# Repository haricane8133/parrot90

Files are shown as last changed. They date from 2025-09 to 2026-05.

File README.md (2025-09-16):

# Parrot 90

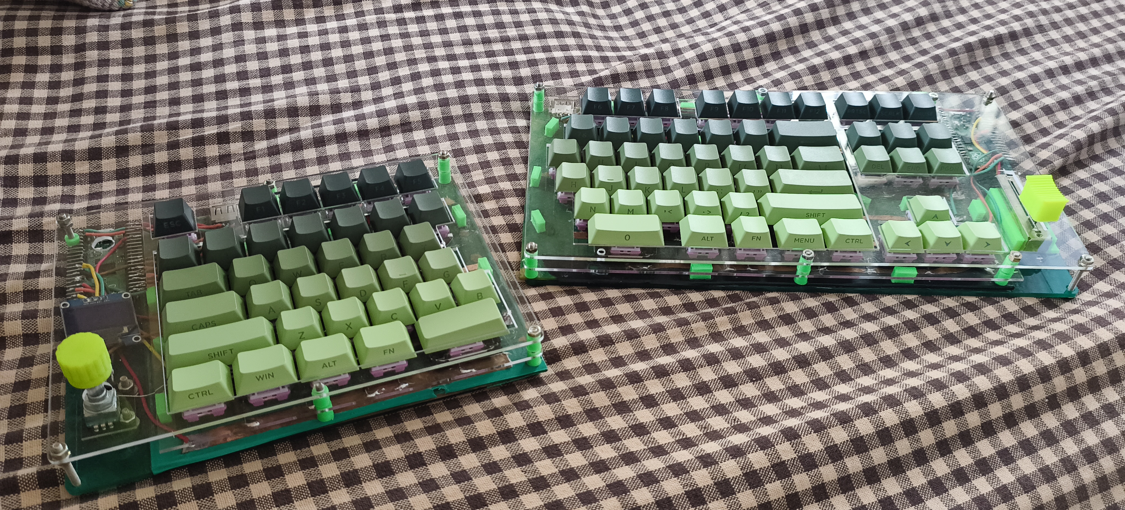
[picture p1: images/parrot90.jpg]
Parrot90

BongoCatSlow
BongoCatFast

Here is a video demo of the keyboard
[https://youtu.be/1Eb73ttOM24](https://youtu.be/1Eb73ttOM24)

This is a home made custom mechanical keyboard. Here are the important points to note
1. Fully home made (including circuit board, excluding switches and keycaps obviously)
2. Circuit board has tin mask and solder mask; designed with old Adobe Photoshop!
3. Hot Swappable
4. TKL Split (90 switches)
5. Rotary encoder
6. Slider Potentiometer (code support coming up)
7. OLED display that shows WPM amd bongo cat gif while typing!
8. Python powered (KMK firmware, CircuitPython)
9. WebSockets / Bluetooth support to connect keyboard with anything (code support coming up)
10. Sandwich type acrylic laser cut case

Here are the switches and keycaps I bought and used for my build (procured through Indian distributors)
* [Akko V3 Creamy Purple Pro](https://en.akkogear.com/product/akko-v3-creamy-purple-pro-switch/)
* [Veekos Forest Gradient Keycap Set](https://www.veekos.com/product/veekos-forest-gradient-keycap-set-135-key/)

Checkout the README files within [/hardware](./hardware/) and [/software](./software/) to know how to build and use one yourself.

But do note that serious hardwork is required as this is a chill non-professional work done with a lot of homebrew / make-shift tools and stuff.

Thanks to @vu2ow for helping out with the build!

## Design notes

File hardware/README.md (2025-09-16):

# Parrot90 Hardware

## Plate / Sandwich case
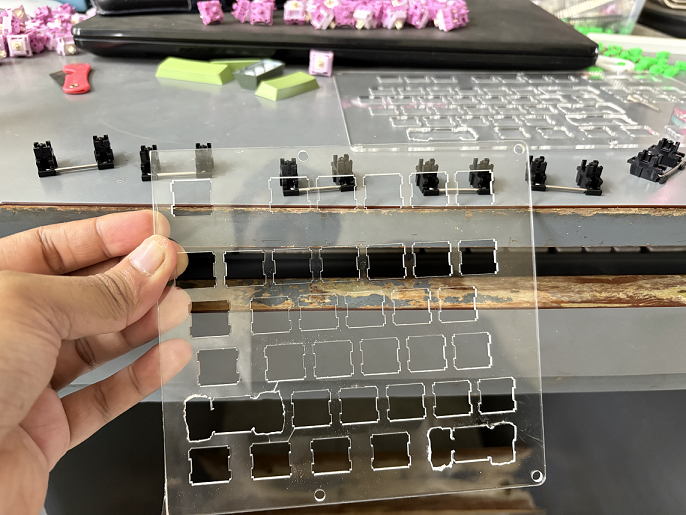
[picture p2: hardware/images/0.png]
Plate design

* The plate design files are available in the `./plate` directory.
* You need to laser cut 1.5mm acrylic sheet. If you use a thicker sheet, then you risk the stabilizers not fixing properly in your plate.
* The files `./plate/left_README.md` and `./plate/right_README.md` files contain the details of the design/layout of the keyboard and the open source websites used.

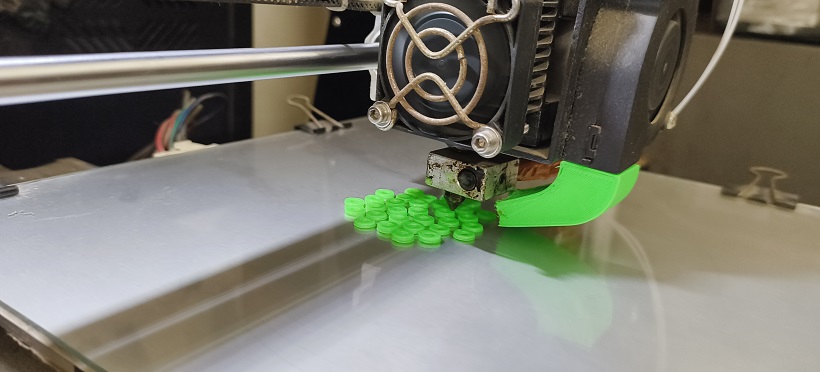
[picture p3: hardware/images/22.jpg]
3D printed fit

If the fit of the switch in the plate and the hotswap socket in the circuit board do not match properly, you need to 3D print some spacers... More details on this below.

## Circuit
* The circuit is already designed. You can just use the images from `./circuit` directory.
* Note: Use caution while using chemicals. Use internet to learn more before doing.

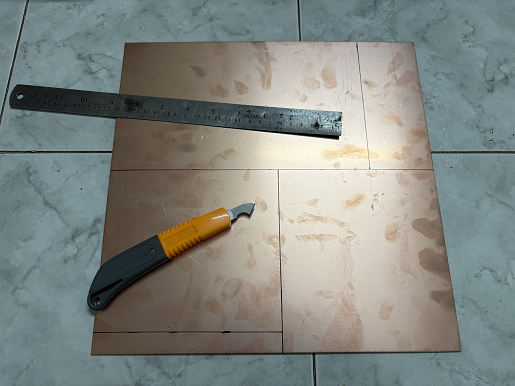
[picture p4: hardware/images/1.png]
Cut the circuit board into right dimensions


Cut the circuit board into right dimensions

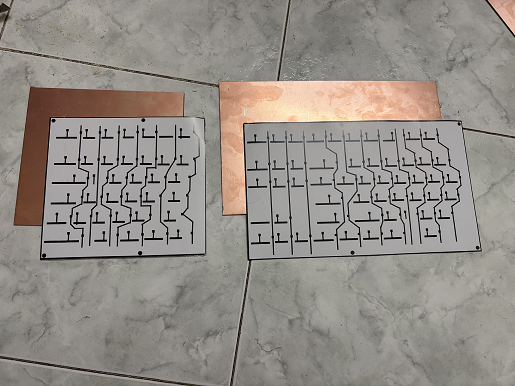
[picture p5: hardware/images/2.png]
Print the circuits in a shiny photo paper using a Laser printer. Make sure to flip the image


Print the circuits in a shiny photo paper using a Laser printer. Make sure to flip the image

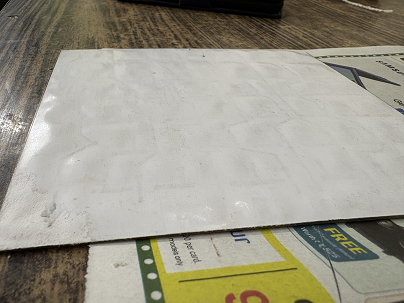
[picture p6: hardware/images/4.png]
... until you see the paper embossing along the plastic


... until you see the paper embossing along the plastic

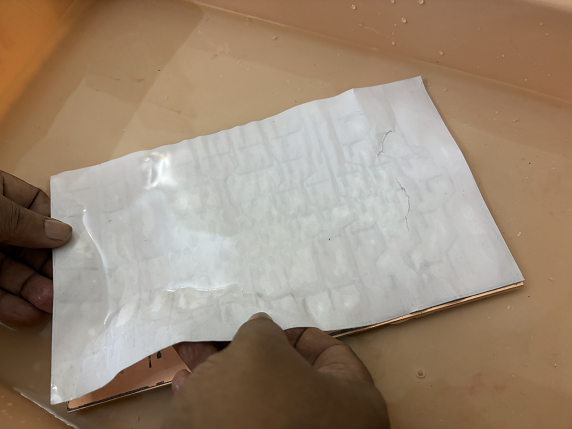
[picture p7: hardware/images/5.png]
Remove the paper. You can use water too


Remove the paper. You can use water too

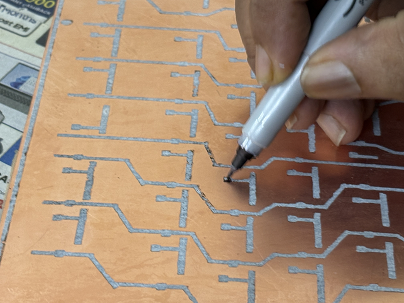
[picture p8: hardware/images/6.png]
Use a permanent marker to sketch out the parts where circuit has broken


Use a permanent marker to sketch out the parts where circuit has broken

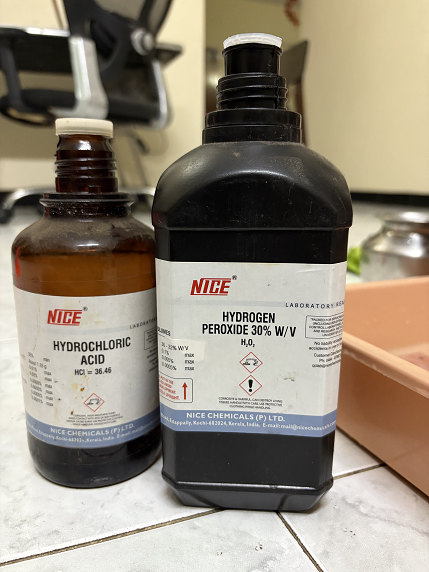
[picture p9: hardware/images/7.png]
Get the chemicals ready for bathing the circuit. Mix them in a plastic container with water


Get the chemicals ready for bathing the circuit. Mix them in a plastic container with water

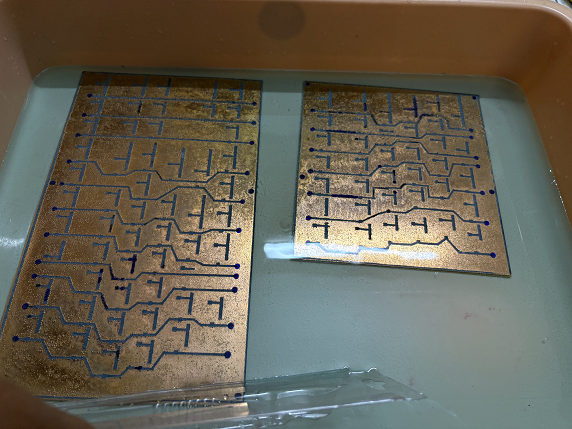
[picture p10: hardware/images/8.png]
Bathe the circuit boards. Make sure to change proportions according to reaction


Bathe the circuit boards. Make sure to change proportions according to reaction

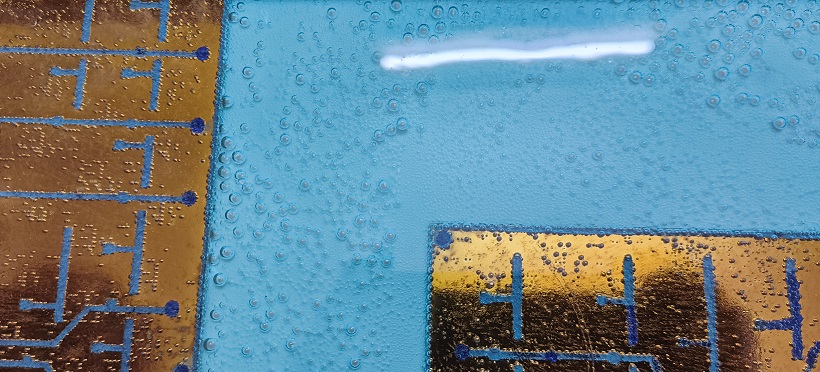
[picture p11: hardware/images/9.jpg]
Fizz indicates that the copper is being dissolved out


Fizz indicates that the copper is being dissolved out

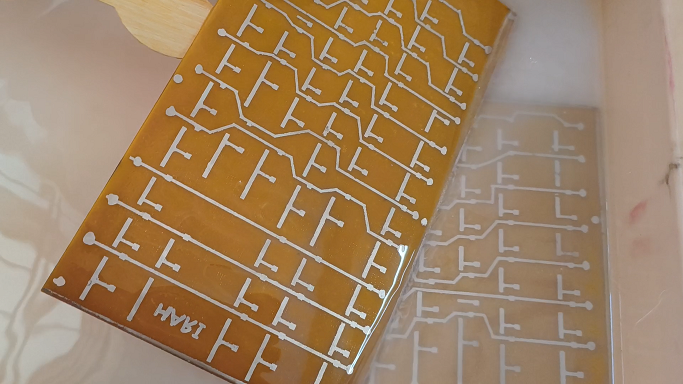
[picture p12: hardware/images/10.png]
Tinning


Wash the boards and prepare them for tinning. Bathe them in Tin Chloride and HCL.

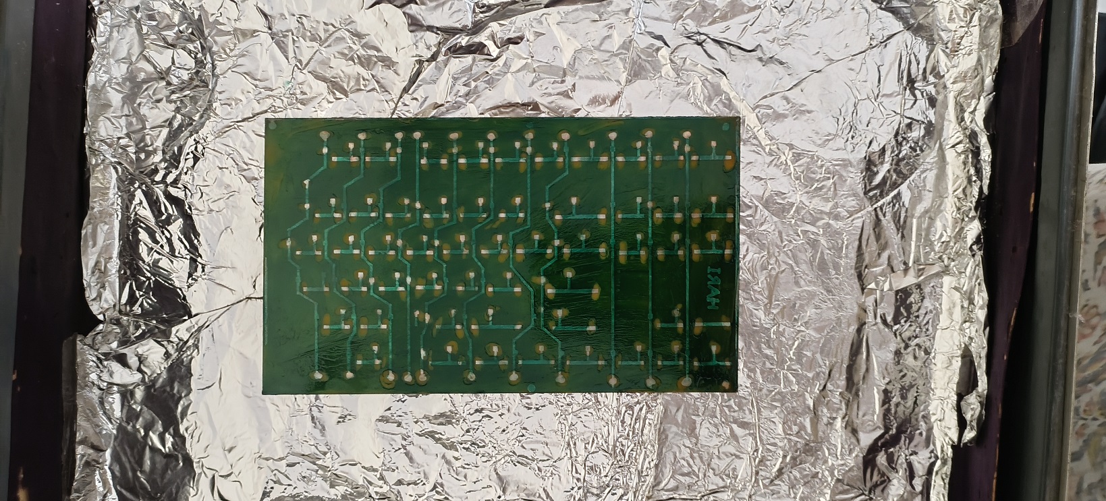
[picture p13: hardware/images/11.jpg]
Use a brush and paint solder mask, except in the places where we have copper/tin


Use a brush and paint solder mask, except in the places where we have copper/tin

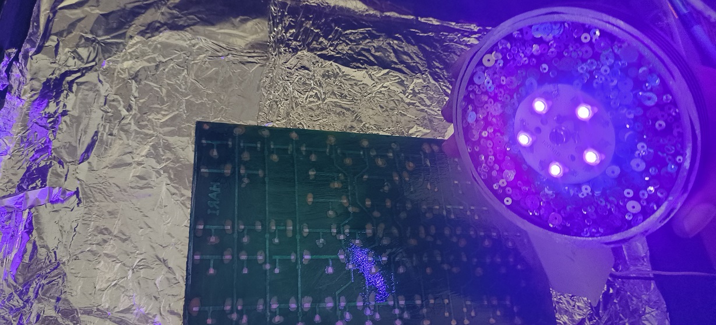
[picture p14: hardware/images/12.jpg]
It is nice to have UV lights shined on them to harden them. Else sunlight for a long time


It is nice to have UV lights shined on them to harden them. Else sunlight for a long time.
In case you notice that you put solder mask over circuit, you need to scrape the layer off later.

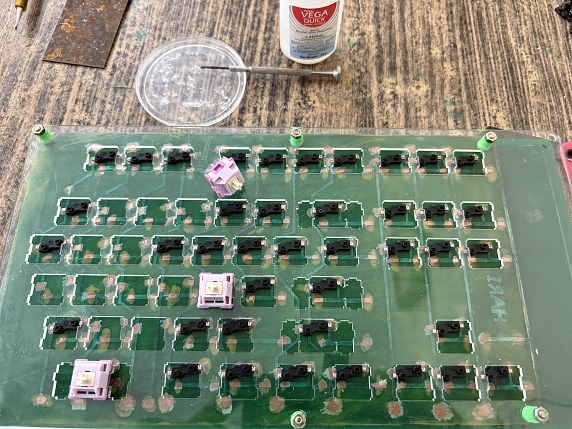
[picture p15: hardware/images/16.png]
Fix the hotswap sockets


Next stage is to assemble hotswap sockets. Here is what you need to do
* First glue the circuit board to the base acrylic plate.
* Second align the switch plate on to the base plate and fasten them tightly.
* Try attach the hotswap sockets to a switch and insert it into the plate.
* Ensure that the bottom of the sockets is exactly touching the circuit boards and the switch is set in the plate.
* Follow the next step in case you need some spacers to be placed to adjust the fit. This is critical
* Then place a quick glue drop on the bottom of the socket and insert the switch into the plate.
* Wait for sometime and pull out the switch. The hotswap should now be fixed to the circuit board at the right place.
* Repeat this for all the switches.

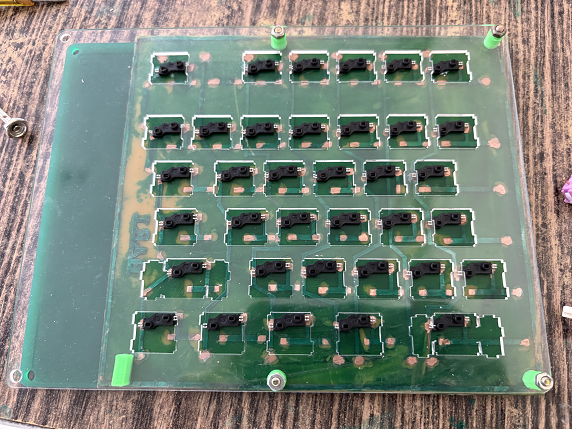
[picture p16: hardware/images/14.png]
You'll have this now


You'll have this now

If the fit of the switch in the plate and the hotswap socket in the circuit board do not match properly, you need to 3D print some spacers...

If the fit of the switch in the plate and the hotswap socket in the circuit board do not match properly, you need to 3D print some spacers...

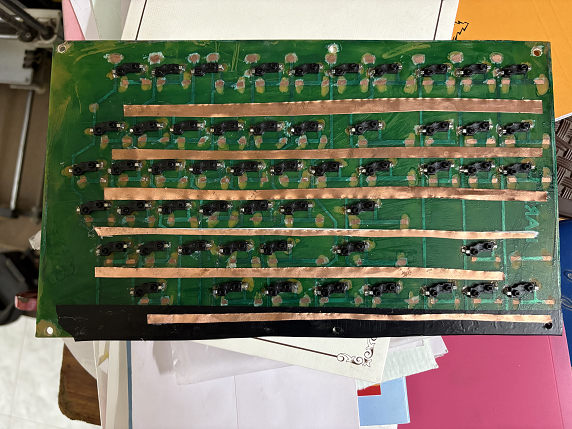
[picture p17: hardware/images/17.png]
Then glue some copper strips for the rows


Then glue some copper strips for the rows

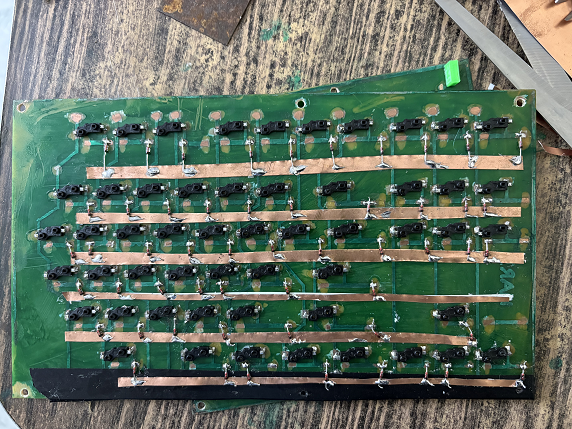
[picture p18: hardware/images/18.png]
Then solder the diodes


Then solder the diodes

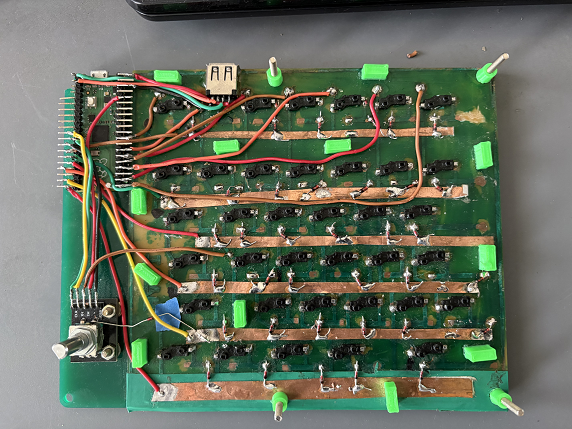
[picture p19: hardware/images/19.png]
Then solder everything else according to the pins marked in code


Then solder everything else according to the pins marked in code. Note the UCB connection between the left half and the right half

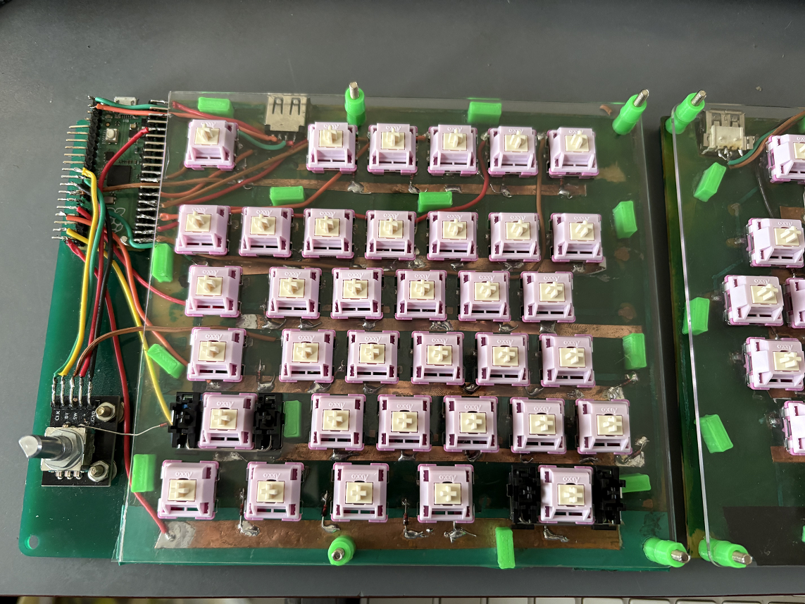
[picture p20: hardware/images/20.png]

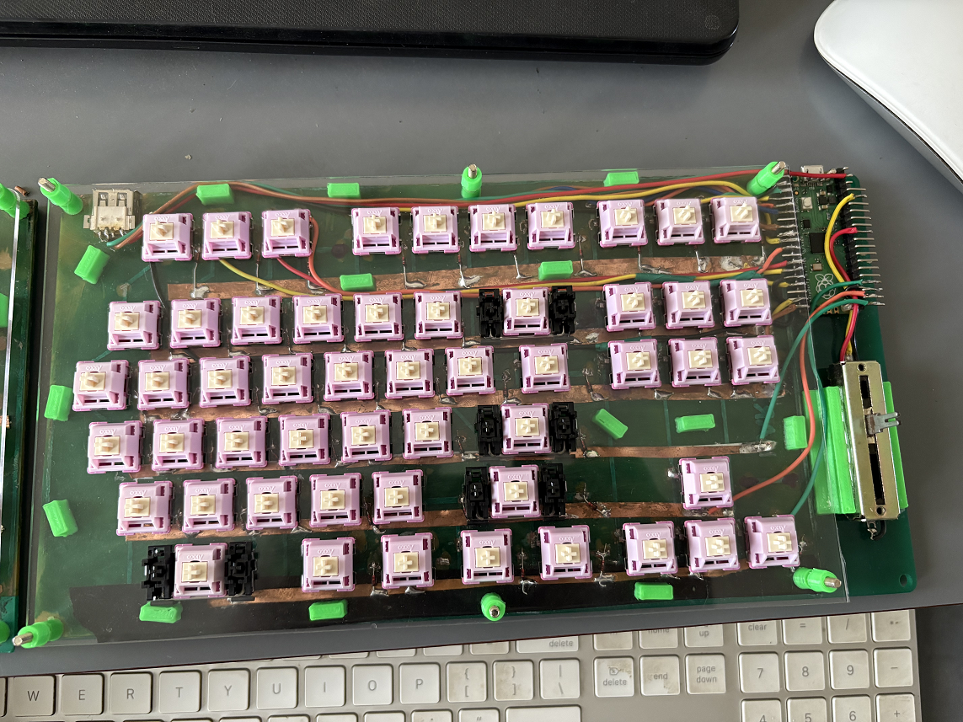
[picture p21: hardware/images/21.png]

Fix the stabilizers, the switches, keycaps and the other plate layers

Fix the stabilizers, the switches, keycaps and the other plate layers

### Some other details
* If you would prefer to handwire instead of a circuit board, that can also be done. Just glue the hotswap directly to the base plate and then solder wires.
* The circuit was designed in Adobe Photoshop by working with images (png, jpg, etc).
* We just have to ensure that all the sizes are accurate - size of switch, size of hotswap socket, etc...

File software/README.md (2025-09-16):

# Parrot90 Software
1. Flash CircuitPython 9.2.8 on the two Raspberry PI Picos. Instructions [here](https://circuitpython.org/)
2. Install latest KMK (copy KMK) to the two picos. Instructions [here](https://github.com/KMKfw/kmk_firmware)
3. Install all library dependencies as mentioned in the following section.
4. Transfer the code from this folder to the two picos
5. Make sure to the underscore from `code.py` and `boot.py` for respective Picos.

### Dependencies
* https://github.com/adafruit/Adafruit_CircuitPython_DisplayIO_SSD1306/releases/download/3.0.3/adafruit-circuitpython-displayio-ssd1306-py-3.0.3.zip
* https://github.com/adafruit/Adafruit_CircuitPython_Display_Text/releases/download/3.3.3/adafruit-circuitpython-display-text-py-3.3.3.zip
* https://github.com/adafruit/Adafruit_CircuitPython_ImageLoad/releases/download/1.24.4/adafruit-circuitpython-imageload-9.x-mpy-1.24.4.zip
Note: After downloading all libraries, just rename their parent folders to the actual library and flatten out the lib folder in the parent so that code can import properly. For Adafruit_CircuitPython_DisplayIO_SSD1306, rename the py file to __init__.py also.

### Debug
If you need to debug through serial port, use the following -
`python -m serial.tools.miniterm COMX 115200`

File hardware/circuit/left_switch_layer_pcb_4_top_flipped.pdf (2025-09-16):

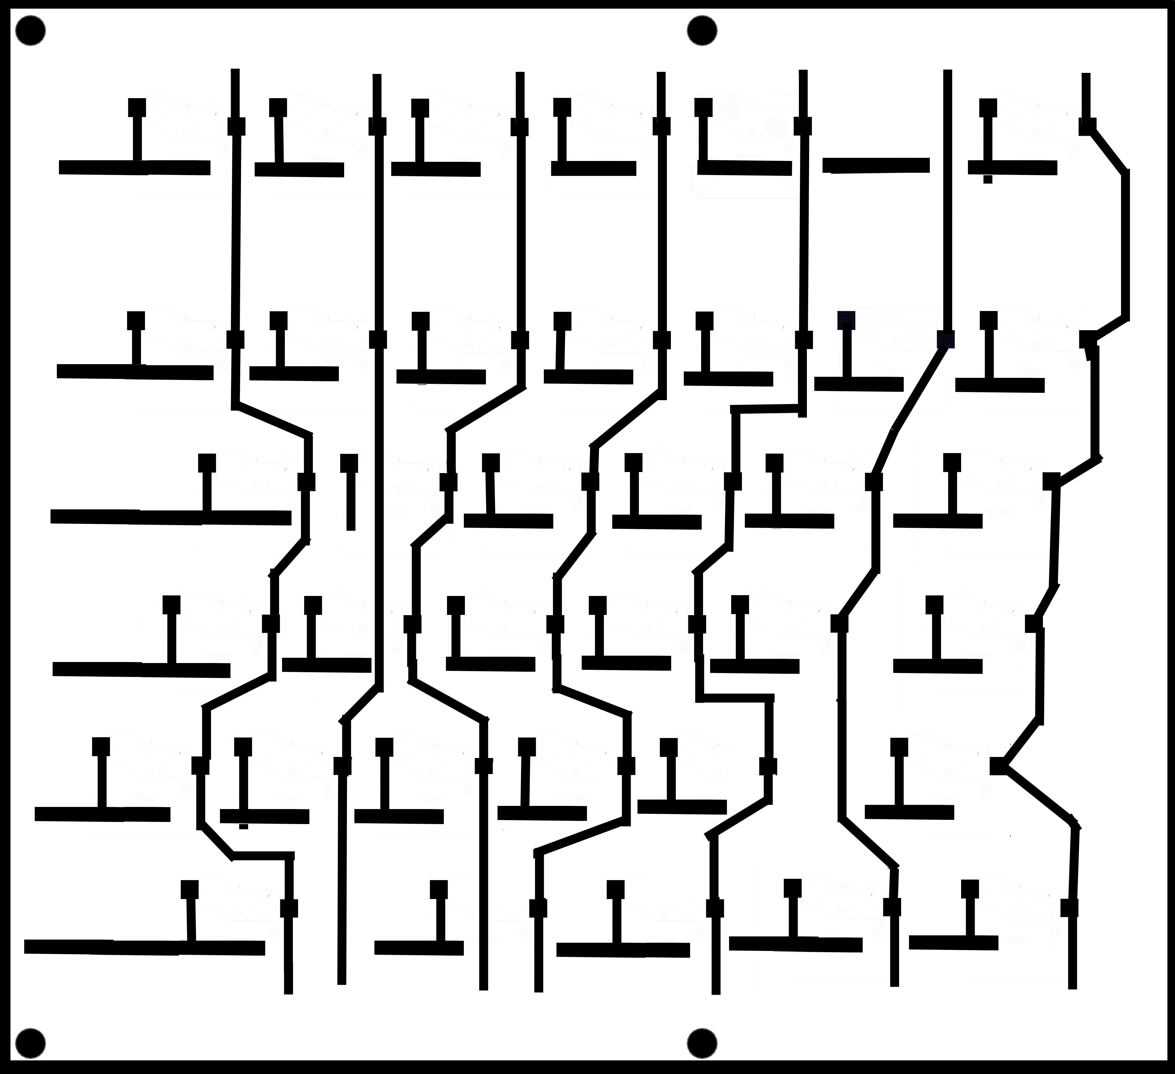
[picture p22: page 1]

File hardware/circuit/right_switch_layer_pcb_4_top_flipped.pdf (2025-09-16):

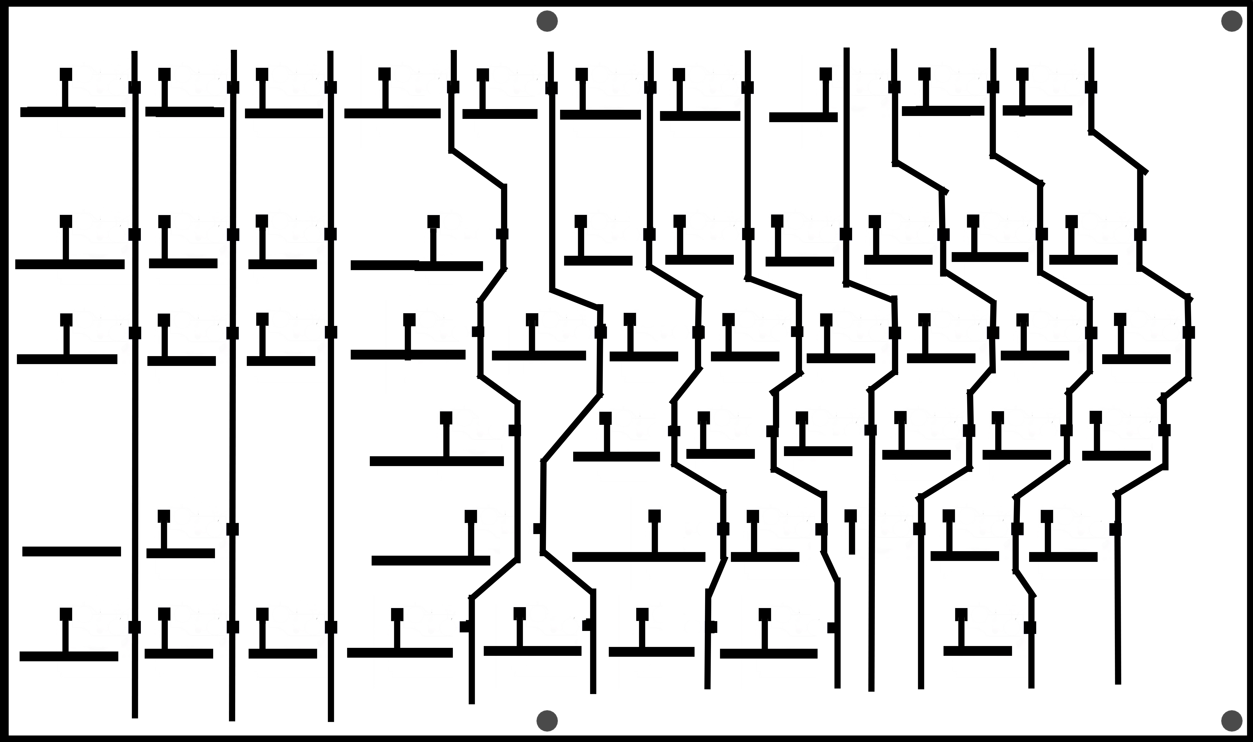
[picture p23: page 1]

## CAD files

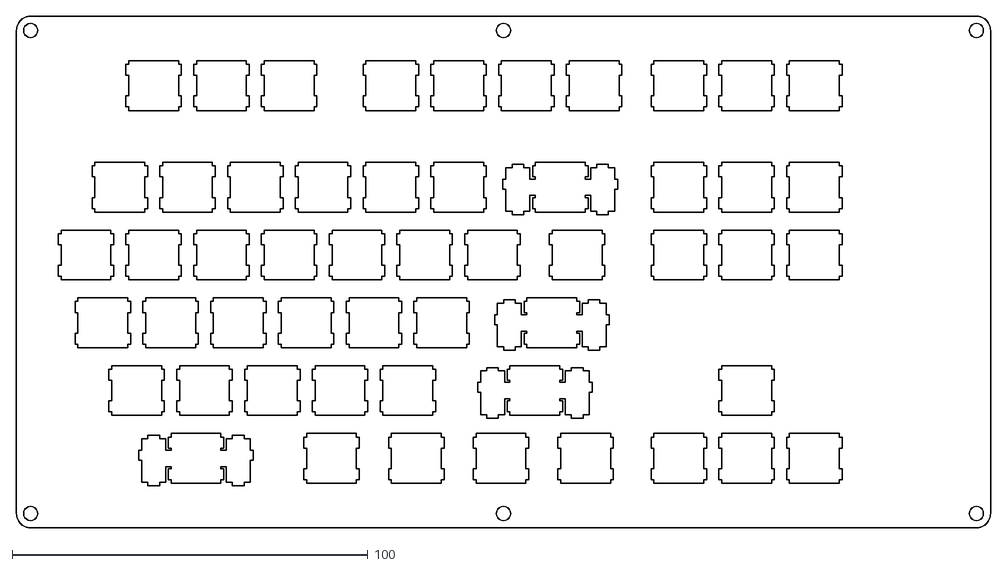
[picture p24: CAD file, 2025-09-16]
hardware/plate/right_switch_layer.dxf
273.8 x 143.8

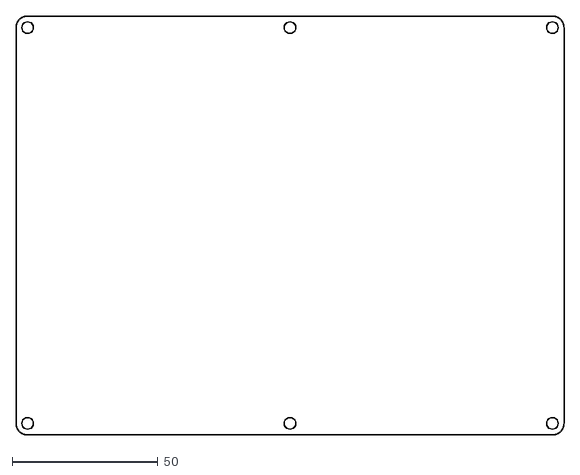
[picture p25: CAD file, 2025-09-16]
hardware/plate/left_bottom_layer.dxf
188.1 x 143.8

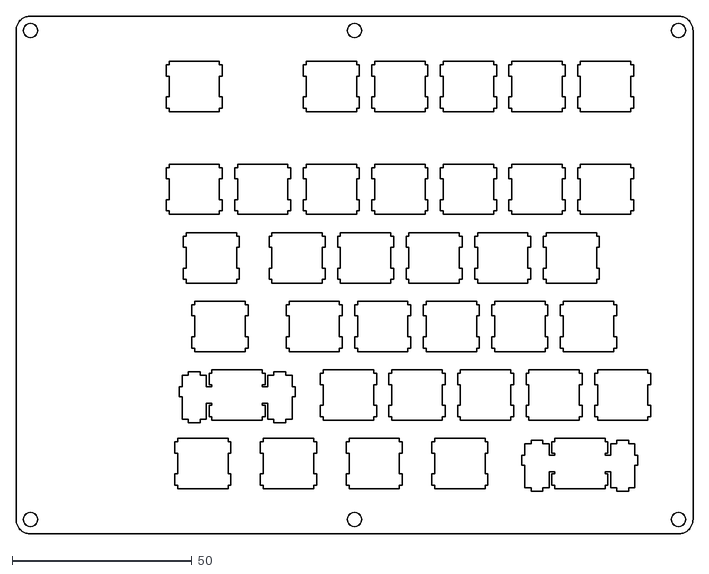
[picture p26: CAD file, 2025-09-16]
hardware/plate/left_switch_layer.dxf
188.1 x 143.8

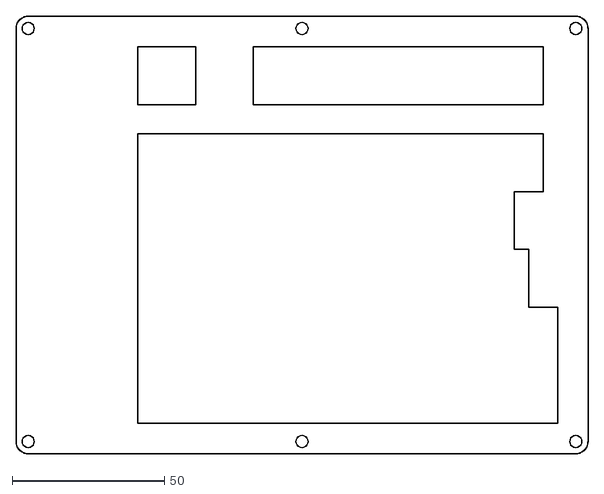
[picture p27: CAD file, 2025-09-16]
hardware/plate/left_top_layer.dxf
188.1 x 143.8

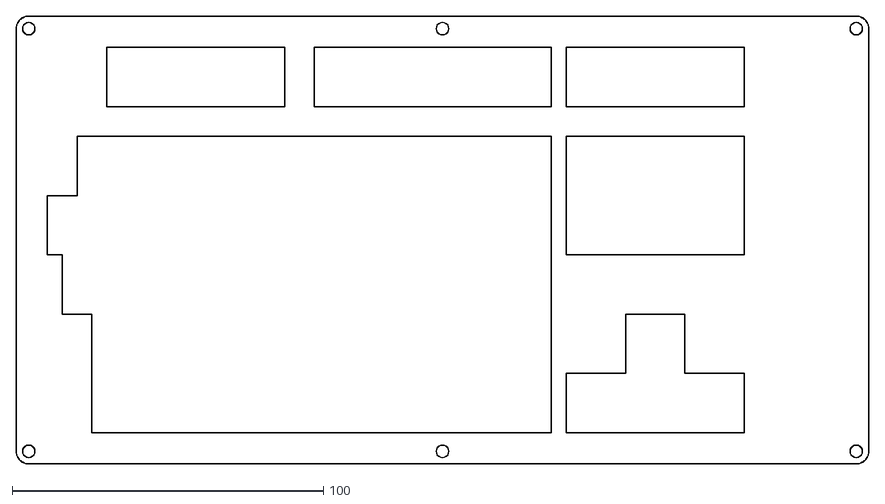
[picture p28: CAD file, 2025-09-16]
hardware/plate/right_top_layer.dxf
273.8 x 143.8

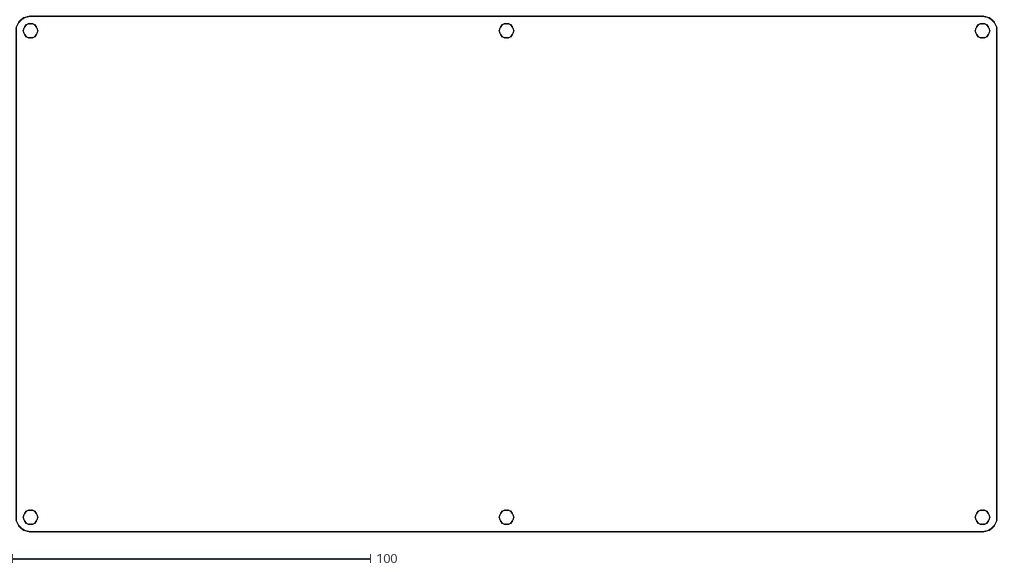
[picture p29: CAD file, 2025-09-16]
hardware/plate/right_bottom_layer.dxf
273.8 x 143.8

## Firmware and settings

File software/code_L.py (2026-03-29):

import sys, time, board, microcontroller # type: ignore

# if microcontroller.nvm[1] == 1:
#     sys.exit()

print("LHS: Starting code.py")

from kmk.kmk_keyboard import KMKKeyboard
from kmk.keys import KC
from kmk.scanners import DiodeOrientation


# Setup
print("LHS: Configuring Keyboard")

keyboard = KMKKeyboard()
keyboard.debug_enabled = False
# if microcontroller.nvm[1] == 1:
#     keyboard.debug_enabled = False

from kmk.modules.split import Split, SplitType, SplitSide
split = Split(
    split_side=SplitSide.LEFT,
    split_target_left=True,
    split_flip=False,
    split_type=SplitType.UART,
    uart_interval = 1,
    split_mapping={
        'rows': 6,
        'left_cols': 7,
        'right_cols': 11,
        'right_start': 66,
        'split_flip': False,
    },
    # use_pio=True,
    data_pin=board.GP1,
    data_pin2=board.GP0,
    # uart_flip = False,
)
split.debug_enabled = False
keyboard.modules.append(split)

from kmk.modules.layers import Layers
keyboard.modules.append(Layers())

from kmk.extensions.media_keys import MediaKeys
keyboard.extensions.append(MediaKeys())

# Asymmetric split: left half has 7 columns, right half has 11 columns.
# Keyboard Config
keyboard.col_pins = (board.GP22, board.GP21, board.GP20, board.GP19, board.GP18, board.GP17, board.GP16)
keyboard.row_pins = (board.GP10, board.GP11, board.GP12, board.GP13, board.GP14, board.GP15)
keyboard.diode_orientation = DiodeOrientation.COL2ROW

# Keyboard Matrices
macMatrix = [
    [
        KC.ESC,   KC.NO,    KC.NO,   KC.NO,    KC.NO,   KC.NO,   KC.NO,                   KC.MRWD, KC.MPLY, KC.MFFD, KC.NO,   KC.MUTE,  KC.VOLD,  KC.VOLU,   KC.NO,    KC.NO,    KC.NO,   KC.NO,
        KC.GRAVE, KC.N1,    KC.N2,   KC.N3,    KC.N4,   KC.N5,   KC.N6,                   KC.N7,   KC.N8,   KC.N9,   KC.N0,   KC.MINUS, KC.EQUAL, KC.NO,     KC.BSPC,  KC.MO(1), KC.HOME, KC.PGUP,
        KC.TAB,   KC.Q,     KC.W,    KC.E,     KC.R,    KC.NO,   KC.T,                    KC.Y,    KC.U,    KC.I,    KC.O,    KC.P,     KC.LBRC,  KC.RBRC,   KC.BSLS,  KC.DEL,   KC.END,  KC.PGDN,
        KC.CAPS,  KC.A,     KC.S,    KC.D,     KC.F,    KC.NO,   KC.G,                    KC.H,    KC.J,    KC.K,    KC.L,    KC.SCLN,  KC.QUOT,  KC.NO,     KC.ENT,   KC.MO,    KC.NO,   KC.NO,
        KC.LSFT,  KC.MUTE,  KC.Z,    KC.X,     KC.C,    KC.V,    KC.B,                    KC.N,    KC.M,    KC.COMM, KC.NO,   KC.DOT,   KC.SLSH,  KC.RSHIFT, KC.NO,    KC.NO,    KC.UP,   KC.NO,
        KC.LCTL,  KC.MO(1), KC.LALT, KC.LGUI,  KC.NO,   KC.NO,   KC.SPC,                  KC.NO,   KC.SPC,  KC.NO,   KC.NO,   KC.RGUI,  KC.RALT,  KC.MO(1),  KC.RCTRL, KC.LEFT,  KC.DOWN, KC.RIGHT
    ],
    [
        KC.TRNS,  KC.TRNS, KC.F1,   KC.F2,    KC.F3,   KC.F4,   KC.F5,                    KC.F6,    KC.F7,   KC.F8,   KC.NO,   KC.F9,   KC.F10,  KC.F11,  KC.F12,  KC.F13,  KC.F14,  KC.F15,
        KC.TRNS,  KC.TRNS, KC.TRNS, KC.TRNS,  KC.TRNS, KC.TRNS, KC.TRNS,                  KC.TRNS,  KC.TRNS, KC.TRNS, KC.TRNS, KC.TRNS, KC.TRNS, KC.TRNS, KC.TRNS, KC.TRNS, KC.TRNS, KC.TRNS,
        KC.TRNS,  KC.TRNS, KC.TRNS, KC.TRNS,  KC.TRNS, KC.TRNS, KC.TRNS,                  KC.TRNS,  KC.TRNS, KC.TRNS, KC.TRNS, KC.TRNS, KC.TRNS, KC.TRNS, KC.TRNS, KC.TRNS, KC.TRNS, KC.TRNS,
        KC.TRNS,  KC.TRNS, KC.TRNS, KC.TRNS,  KC.TRNS, KC.TRNS, KC.TRNS,                  KC.TRNS,  KC.TRNS, KC.TRNS, KC.TRNS, KC.TRNS, KC.TRNS, KC.TRNS, KC.TRNS, KC.TRNS, KC.TRNS, KC.TRNS,
        KC.TRNS,  KC.TRNS, KC.TRNS, KC.TRNS,  KC.TRNS, KC.TRNS, KC.TRNS,                  KC.TRNS,  KC.TRNS, KC.TRNS, KC.TRNS, KC.TRNS, KC.TRNS, KC.TRNS, KC.TRNS, KC.TRNS, KC.TRNS, KC.TRNS,
        KC.TRNS,  KC.TRNS, KC.TRNS, KC.TRNS,  KC.TRNS, KC.TRNS, KC.TRNS,                  KC.TRNS,  KC.TRNS, KC.TRNS, KC.TRNS, KC.TRNS, KC.TRNS, KC.TRNS, KC.TRNS, KC.TRNS, KC.TRNS, KC.TRNS
    ],
]
winMatrix = [
    [
        KC.ESC,   KC.NO,    KC.F1,   KC.F2,    KC.F3,   KC.F4,   KC.F5,                   KC.F6,   KC.F7,   KC.F8,   KC.NO,   KC.F9,    KC.F10,   KC.F11,    KC.F12,    KC.PSCREEN,       KC.SLCK, KC.PAUSE,
        KC.GRAVE, KC.N1,    KC.N2,   KC.N3,    KC.N4,   KC.N5,   KC.N6,                   KC.N7,   KC.N8,   KC.N9,   KC.N0,   KC.MINUS, KC.EQUAL, KC.NO,     KC.BSPC,   KC.LT(1, KC.INS), KC.HOME, KC.PGUP,
        KC.TAB,   KC.Q,     KC.W,    KC.E,     KC.R,    KC.NO,   KC.T,                    KC.Y,    KC.U,    KC.I,    KC.O,    KC.P,     KC.LBRC,  KC.RBRC,   KC.BSLS,   KC.DEL,           KC.END,  KC.PGDN,
        KC.CAPS,  KC.A,     KC.S,    KC.D,     KC.F,    KC.NO,   KC.G,                    KC.H,    KC.J,    KC.K,    KC.L,    KC.SCLN,  KC.QUOT,  KC.NO,     KC.ENT,    KC.NO,            KC.NO,   KC.NO,
        KC.LSFT,  KC.MUTE,  KC.Z,    KC.X,     KC.C,    KC.V,    KC.B,                    KC.N,    KC.M,    KC.COMM, KC.NO,   KC.DOT,   KC.SLSH,  KC.RSHIFT, KC.NO,     KC.NO,            KC.UP,   KC.NO,
        KC.LCTL,  KC.MO(1), KC.LGUI, KC.LALT,  KC.NO,   KC.NO,   KC.SPC,                  KC.NO,   KC.SPC,  KC.NO,   KC.NO,   KC.RALT,  KC.RGUI,  KC.MO(1),  KC.RCTRL,  KC.LEFT,          KC.DOWN, KC.RIGHT
    ],
    [
        KC.TRNS,  KC.TRNS, KC.NO,   KC.NO,   KC.NO,   KC.NO,   KC.NO,                     KC.MPRV,  KC.MPLY, KC.MNXT, KC.TRNS, KC.MUTE, KC.VOLD, KC.VOLU, KC.TRNS, KC.TRNS, KC.TRNS, KC.TRNS,
        KC.TRNS,  KC.TRNS, KC.TRNS, KC.TRNS, KC.TRNS, KC.TRNS, KC.TRNS,                   KC.TRNS,  KC.TRNS, KC.TRNS, KC.TRNS, KC.TRNS, KC.TRNS, KC.TRNS, KC.TRNS, KC.TRNS, KC.TRNS, KC.TRNS,
        KC.TRNS,  KC.TRNS, KC.TRNS, KC.TRNS, KC.TRNS, KC.TRNS, KC.TRNS,                   KC.TRNS,  KC.TRNS, KC.TRNS, KC.TRNS, KC.TRNS, KC.TRNS, KC.TRNS, KC.TRNS, KC.TRNS, KC.TRNS, KC.TRNS,
        KC.TRNS,  KC.TRNS, KC.TRNS, KC.TRNS, KC.TRNS, KC.TRNS, KC.TRNS,                   KC.TRNS,  KC.TRNS, KC.TRNS, KC.TRNS, KC.TRNS, KC.TRNS, KC.TRNS, KC.TRNS, KC.TRNS, KC.TRNS, KC.TRNS,
        KC.TRNS,  KC.TRNS, KC.TRNS, KC.TRNS, KC.TRNS, KC.TRNS, KC.TRNS,                   KC.TRNS,  KC.TRNS, KC.TRNS, KC.TRNS, KC.TRNS, KC.TRNS, KC.TRNS, KC.TRNS, KC.TRNS, KC.TRNS, KC.TRNS,
        KC.TRNS,  KC.TRNS, KC.TRNS, KC.TRNS, KC.TRNS, KC.TRNS, KC.TRNS,                   KC.TRNS,  KC.TRNS, KC.TRNS, KC.TRNS, KC.TRNS, KC.TRNS, KC.TRNS, KC.TRNS, KC.TRNS, KC.TRNS, KC.TRNS
    ],
]

if(microcontroller.nvm[2] == 0):
    keyboard.keymap = winMatrix
else:
    keyboard.keymap = macMatrix


# Rotary Encoder (only the rotating part. The button is included in the above keyboard matrix)
from kmk.modules.encoder import EncoderHandler
encoder_handler = EncoderHandler()
encoder_handler.pins = [(board.GP9, board.GP8, None, False)]
encoder_handler.map = [[(KC.VOLD, KC.VOLU, KC.NO)]]
keyboard.modules.append(encoder_handler)





print("LHS: Starting Display")

ENABLE_GIF_WPM = microcontroller.nvm[3] == 1

from random import randint
import busio, displayio, terminalio, i2cdisplaybus
from adafruit_display_text import label
from adafruit_displayio_ssd1306 import SSD1306
from kmk.extensions.lock_status import LockStatus


NAME = "Parrot90"
message1 = ["Greeny", "Parrot", "Parakeet", "Canopy", "Parakeeb", "Leaves", "Forrest", "KeeBird"]

WIDTH = 128
HEIGHT = 64
ROTATION = 0
BORDER = 1


displayio.release_displays()

# --- Initialize I2C
i2c = busio.I2C(board.GP3, board.GP2)   # SCL=GP3, SDA=GP2

# --- Create the I2C display bus
display_bus = displayio.I2CDisplay(i2c, device_address=0x3C)


# i2c = busio.I2C(scl=board.GP3, sda=board.GP2)
# i2c_display = i2cdisplaybus.I2CDisplayBus(i2c, device_address=0x3C)

display = SSD1306(display_bus, width=WIDTH, height=HEIGHT, rotation=ROTATION)

# Create the root group
mainGrp = displayio.Group()


display.root_group = mainGrp

# Outer white background
color_bitmap = displayio.Bitmap(WIDTH, HEIGHT, 1)
color_palette = displayio.Palette(1)
color_palette[0] = 0xFFFFFF
bg_sprite = displayio.TileGrid(color_bitmap, pixel_shader=color_palette, x=0, y=0)

# Border outline only (palette index 0 will be made transparent)
border_bitmap = displayio.Bitmap(WIDTH, HEIGHT, 2)
border_palette = displayio.Palette(2)
border_palette[0] = 0x000000           # interior (will be made transparent)
border_palette[1] = 0xFFFFFF           # border color (white)

# Draw border lines (only set index 1 on the outline pixels)
for x in range(WIDTH):
    border_bitmap[x, 0] = 1            # top
    border_bitmap[x, HEIGHT - 1] = 1   # bottom
for y in range(HEIGHT):
    border_bitmap[0, y] = 1            # left
    border_bitmap[WIDTH - 1, y] = 1    # right

border_sprite = displayio.TileGrid(border_bitmap, pixel_shader=border_palette, x=0, y=0)



# Banner
banner = label.Label(terminalio.FONT, text=NAME, color=0xFFFFFF, x=18, y=7, scale=2)

# Mode
mode_text = '"' + message1[randint(0, len(message1)-1)] + '"'
if microcontroller.nvm[1] == 1:
    mode_text = "<service mode>"
mode_label = label.Label(terminalio.FONT, text=mode_text, color=0xFFFFFF, x=3, y=23)

# Host
hostText = "<Mac>" if microcontroller.nvm[2] else "<Win>"
host_label = label.Label(terminalio.FONT, text=hostText, color=0xFFFFFF, x=93, y=23)

# Caps Lock symbol
caps_label1 = label.Label(terminalio.FONT, text="^", color=0xFFFFFF, x=5, y=17, scale=2)
caps_label2 = label.Label(terminalio.FONT, text="^", color=0xFFFFFF, x=115, y=17, scale=2)

class _LockStatus(LockStatus):
    def after_hid_send(self, sandbox):
        super().after_hid_send(sandbox)
        if self.get_caps_lock():
            if caps_label1 not in mainGrp:
                mainGrp.append(caps_label1)
            if caps_label2 not in mainGrp:
                mainGrp.append(caps_label2)
        else:
            if caps_label1 in mainGrp:
                mainGrp.remove(caps_label1)
            if caps_label2 in mainGrp:
                mainGrp.remove(caps_label2)

keyboard.extensions.append(_LockStatus())

# The big Hari logo
hari_label = label.Label(terminalio.FONT, text="HARI", color=0xFFFFFF, x=20, y=46, scale=4)

# -------------------------------
# Bongo Cat Gif
# -------------------------------
import adafruit_imageload

keys_typed = 0
type_start_time = None
last_key_time = None
last_oled_wpm_time = None
last_oled_gif_time = time.monotonic()
last_oled_loop_time = None
current_gif_type = 0 # 0 means slow cat gif and 1 means fast cat gif

OLED_MIN_LOOP_INTERVAL = 0.10
WPM_UPDATE_INTERVAL = 0.5
COUNT_RESET_TIME = 5
GIF_WPM_THRESHOLD = 10
GIF_TIME_THRESHOLD = 1
GIF_SLOW_UPDATE_INTERVAL = 0.25
GIF_FAST_UPDATE_INTERVAL = 0.20
DISPLAY_TYPING_SUPPRESS = 0.12

# Load frames
def load_animation(path, frame_count):
    frames = []
    for i in range(frame_count):
        bmp, pal = adafruit_imageload.load(f"{path}/{i}.bmp",
                                           bitmap=displayio.Bitmap,
                                           palette=displayio.Palette)
        frames.append((bmp, pal))
    return frames

cat_slow_frames = load_animation("/images/gif_slow", 5)
cat_fast_frames = load_animation("/images/gif_fast", 3)


# Setup TileGrid for display
current_frame = 0

bmp, pal = cat_slow_frames[0]
anim_sprite = None
if ENABLE_GIF_WPM:
    anim_sprite = displayio.TileGrid(bmp, pixel_shader=pal, x=30, y=28)

def display_is_busy():
    if split._uart is not None and split._uart.in_waiting > 0:
        return True
    if last_key_time is not None and (time.monotonic() - last_key_time) < DISPLAY_TYPING_SUPPRESS:
        return True
    return False

def show_frame(bmp, pal):
    global anim_sprite, current_gif_type, last_oled_gif_time, GIF_SLOW_UPDATE_INTERVAL, GIF_FAST_UPDATE_INTERVAL
    if anim_sprite is None:
        return False

    now = time.monotonic()

    update_interval = GIF_SLOW_UPDATE_INTERVAL
    if (current_gif_type != 0):
        update_interval = GIF_FAST_UPDATE_INTERVAL
    
    if(now - last_oled_gif_time) > update_interval:
        anim_sprite.bitmap = bmp
        anim_sprite.pixel_shader = pal
        last_oled_gif_time = now
        return True
    return False


# Animation update
def update_animation(wpm):
    global cat_fast_frames, cat_slow_frames, current_frame, current_gif_type, type_start_time, GIF_WPM_THRESHOLD, GIF_TIME_THRESHOLD

    now = time.monotonic()

    type_start_duration = (now - (now if type_start_time == None else type_start_time))
    type_end_duration = (now - (now if last_key_time == None else last_key_time))
    
    # Pick animation set
    if wpm > GIF_WPM_THRESHOLD and type_start_duration >= GIF_TIME_THRESHOLD and type_end_duration < GIF_TIME_THRESHOLD:
        # Fast CAT GIF
        if current_gif_type == 0:
            current_frame = 0
            current_gif_type = 1
        frames = cat_fast_frames
    else:
        # Slow Cat GIF
        if current_gif_type == 1:
            current_frame = 0
            current_gif_type = 0
        frames = cat_slow_frames

    current_frame = current_frame % len(frames)

    bmp, pal = frames[current_frame]
    if show_frame(bmp, pal):
        current_frame += 1

# -------------------------------
# WPM tracking (reset after idle)
# -------------------------------
from kmk.keys import KC

wpm_label = None
if ENABLE_GIF_WPM:
    wpm_label = label.Label(terminalio.FONT, text="WPM: 0", color=0xFFFFFF, x=3, y=50)

def get_wpm():
    global keys_typed, type_start_time
    if not type_start_time or keys_typed == 0:
        return 0
    elapsed = time.monotonic() - type_start_time
    if elapsed <= 0:
        return 0
    return int((keys_typed / 5) * 60 / elapsed)

# Wrap KMK process_key
orig_process_key = keyboard.process_key

def counting_process_key(key, is_pressed, int_coord=None):
    global keys_typed, type_start_time, last_key_time

    now = time.monotonic()

    if is_pressed:
        if keys_typed == 0:
            type_start_time = now
        keys_typed += 1
        last_key_time = now

    return orig_process_key(key, is_pressed, int_coord)

if ENABLE_GIF_WPM:
    keyboard.process_key = counting_process_key

# Continuous update (so WPM drops to 0 if reset or idle)
def update_wpm():
    global keys_typed, type_start_time, last_oled_wpm_time, last_key_time, last_oled_loop_time, WPM_UPDATE_INTERVAL, COUNT_RESET_TIME

    if wpm_label == None:
        return
    if display_is_busy():
        return

    now = time.monotonic()
    if last_oled_loop_time is not None and (now - last_oled_loop_time) < OLED_MIN_LOOP_INTERVAL:
        return
    last_oled_loop_time = now

    wpm = get_wpm()

    if last_key_time and now - last_key_time >= COUNT_RESET_TIME:
        # Reset if idle for some times
        keys_typed = 0
        type_start_time = None

    if last_oled_wpm_time == None or ((now - last_oled_wpm_time) > WPM_UPDATE_INTERVAL):
        wpm_label.text = f"WPM: {wpm}"
        last_oled_wpm_time = now
    
    update_animation(wpm)

# Save the original hook
orig_before_matrix_scan = keyboard.before_matrix_scan

def combined_before_matrix_scan():
    update_wpm()                  # your function
    if orig_before_matrix_scan:   # call the original, if it exists
        orig_before_matrix_scan()

if ENABLE_GIF_WPM:
    keyboard.before_matrix_scan = combined_before_matrix_scan


# -------------------------------

mainGrp.append(bg_sprite)
mainGrp.append(border_sprite)
if ENABLE_GIF_WPM and anim_sprite is not None:
    mainGrp.append(anim_sprite)
mainGrp.append(banner)
mainGrp.append(mode_label)
mainGrp.append(host_label)
mainGrp.append(caps_label1)
mainGrp.append(caps_label2)
if ENABLE_GIF_WPM and wpm_label is not None:
    mainGrp.append(wpm_label)
if not ENABLE_GIF_WPM and hari_label is not None:
    mainGrp.append(hari_label)

if __name__ == '__main__':
    print("LHS: Firing up Keyboard!")
    keyboard.go()

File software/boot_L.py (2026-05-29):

import microcontroller, board, digitalio, storage, usb_cdc, usb_midi

print("LHS: Starting boot.py")

# This might be required to handle the high memory requirements of Adafruit's OLED libraries 
# But this is deprecated in CircuitPython 9. We have to find an alternative.
# import supervisor
# supervisor.set_next_stack_limit(4096 + 4096)

# The following code is to read button presses as the keyboard is booting up,
# to put the keyboard in specific states - maintenance mode, Keyboard Mode (Mac Mode, Windows Mode),
# or to enable certain features
# (maintenance mode is where we enable the USB storage for transfering code)

# To put the keyboard in maintenance mode, the user has to...
#     press the encoder button (the one you have configured for mute)
# To set the keyboard with Mac's keyconfigs, the user has to...
#     press the left CMD button (the one marked as ALT), when the keyboard is first connected
# To make the keyboard work with Windows' keyconfigs, the user has to...
#     press the left Windows button (the one marked as WIN), when the keyboard is first connected
# To enable WS connect experimental function, the user has to...
#     press the left Fn button, when the keyboard is first connected

# * Rotary Encoder button is connected to Row 5, Col 2
# * Windows Button is connected to Row 6, Col 3
# * Mac Button is connected to Row 6, Col 4
# * Fn Button is connected to Row 6, Col 2

# We are able to acheive this by mimicing the Keyboard Matrix.
# Since we are in COL2ROW diode orientation, we provide a voltage in column and check if row is high

# These are the variables that we set to indicate the status. We read this in code.py to customize the state of the keyboard.
# microcontroller.nvm[0] = 0 indicates that THIS SPLIT is the LEFT split (even though there are better methods provided by QMK, let us have this variable)
# microcontroller.nvm[0] = 1 indicates that THIS SPLIT is the RIGHT split (even though there are better methods provided by QMK, let us have this variable)
# microcontroller.nvm[1] = 1 indicates that the keyboard is started along with the USB storage (maintenance Mode)
# microcontroller.nvm[1] = 0 indicates that the keyboard is started normally (Keyboard Mode)
# microcontroller.nvm[2] = 0 indicates that the keyboard is set for Windows
# microcontroller.nvm[2] = 1 indicates that the keyboard is set for Mac
# microcontroller.nvm[3] = 0 indicates that the keyboard is NOT enabled to show cat Gif and WPM
# microcontroller.nvm[3] = 1 indicates that the keyboard is enabled to show cat Gif and WPM

# Note that once KMK is started, we will have to set variables in the KMK Object so that these values are shared with the other half

# This is the Left side
microcontroller.nvm[0] = 0


# Initialize pins
col2 = digitalio.DigitalInOut(board.GP21)
col2.direction = digitalio.Direction.OUTPUT

col3 = digitalio.DigitalInOut(board.GP20)
col3.direction = digitalio.Direction.OUTPUT

col4 = digitalio.DigitalInOut(board.GP19)
col4.direction = digitalio.Direction.OUTPUT

row5 = digitalio.DigitalInOut(board.GP14)
row5.direction = digitalio.Direction.INPUT
row5.pull = digitalio.Pull.DOWN

row6 = digitalio.DigitalInOut(board.GP15)
row6.direction = digitalio.Direction.INPUT
row6.pull = digitalio.Pull.DOWN



# 1. Check Rotary Button press - to put in maintenance mode
col2.value = True
if row5.value:
  # maintenance Mode
  microcontroller.nvm[1] = 1
else:
  # Keyboard Mode
  microcontroller.nvm[1] = 0
  storage.disable_usb_drive()
  usb_cdc.disable()
  # usb_midi.disable()
col2.value = False

# 2.a) Read Alt Button Press - To put the keyboard in Mac Mode
col4.value = True
MAC_PRESSED = False
if row6.value:
  MAC_PRESSED = True
  microcontroller.nvm[2] = 1
col4.value = False

# 2.b) Check Windows Button press - To put in Windows mode
col3.value = True
if row6.value and not MAC_PRESSED:
  microcontroller.nvm[2] = 0
col3.value = False


# 3) Turn on Cat GIF and WPM
col2.value = True
microcontroller.nvm[3] = 0
if row6.value:
  microcontroller.nvm[3] = 1
col2.value = False


col2.deinit()
col3.deinit()
col4.deinit()
row5.deinit()
row6.deinit()


if(microcontroller.nvm[1] == 1):
  print('LHS: Keyboard put in Maintainance mode. USB Storage enabled.')

if(microcontroller.nvm[2] == 0):
  print('LHS: Keyboard working in Windows Mode')
else:
  print('LHS: Keyboard working in Mac Mode')

if(microcontroller.nvm[3] == 1):
  print('LHS: Turn on Gif and WPM')

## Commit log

2026-03-22 feat: migrate split to asymmetric split_mapping and remove dummy workaround
    This commit updates Parrot90 split firmware to use the newly introduced
    KMK asymmetric split mapping support via `split_mapping`.
    We have raised a PR to KMK here -
    https://github.com/KMKfw/kmk_firmware/pull/1136
    - Replaced manual/dummy asymmetric split handling with `split_mapping` in both halves.
    - Removed dependency on padded/dummy matrix assumptions for split compatibility.
    - Kept existing keymap indexing behavior by explicitly setting right-half base index.
    - Updated split config on both `code_L.py` and `code_R.py` to use:
    - `rows`
    - `left_cols`
    - `right_cols`
    - `right_start`
    - `split_flip`
    The previ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
    [code_L.py, code_R.py]
2026-03-29 Disable Debug; Reduce KMK UART interval
